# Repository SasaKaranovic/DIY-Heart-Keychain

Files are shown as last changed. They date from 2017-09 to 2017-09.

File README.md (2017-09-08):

# DIY-Heart-Keychain

Check it out on [SasaKaranovic.com/projects/diy-heart-keychain][1]

This one is a very simple but cool project, something that I would recommend to anyone who is interested into DIY electronics, gadgets and learning new stuff in general. 

It is definitely one of those projects that don’t require too much time but you can learn a lot by making it and also earn a lot of credit by sharing it with your friends and family.

### See it in action
Front side of Heart Keychain in Hand (http://sasakaranovic.com/wp-content/uploads/2017/09/InHand_Front-Preview.jpg)

Back side of Heart Keychain in Hand (http://sasakaranovic.com/wp-content/uploads/2017/09/InHand_Back-Preview.jpg)


Heart Keychain in Action (http://sasakaranovic.com/wp-content/uploads/2017/09/InHand-Raw-600px.gif)

### Schematic and PCB

Schematic (http://sasakaranovic.com/wp-content/uploads/2017/09/Schematic.png)

Schematic (http://sasakaranovic.com/wp-content/uploads/2017/09/PCB-Front-and-Back.png)

## Find out more cool projects 

Find more cool projects on my [website][1].

Also feel free to follow me on social media:
[SasaKaranovic.com][2] - [YouTube][3] - [Facebook][4] - [Twitter][5] - [LinkedIn][6]

  [1]: http://sasakaranovic.com/projects/diy-heart-keychain/
  [2]: http://sasakaranovic.com/
  [3]: http://sasakaranovic.com/youtube
  [4]: http://sasakaranovic.com/facebook
  [5]: http://sasakaranovic.com/twitter
  [6]: http://sasakaranovic.com/linkedin

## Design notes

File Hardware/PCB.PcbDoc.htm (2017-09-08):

Reporting Options

# File in Previous Format

Date | : | 2017-09-05
Time | : | 00:32:28
Filename | : | D:\_SocialMedia_\SasaKaranovic.com\GitHub\2017-09-05-DIY-Heart-Keychain\Source files\Design Files\PCB.PcbDoc

Version | Warning

This file was generated by an earlier version of the software

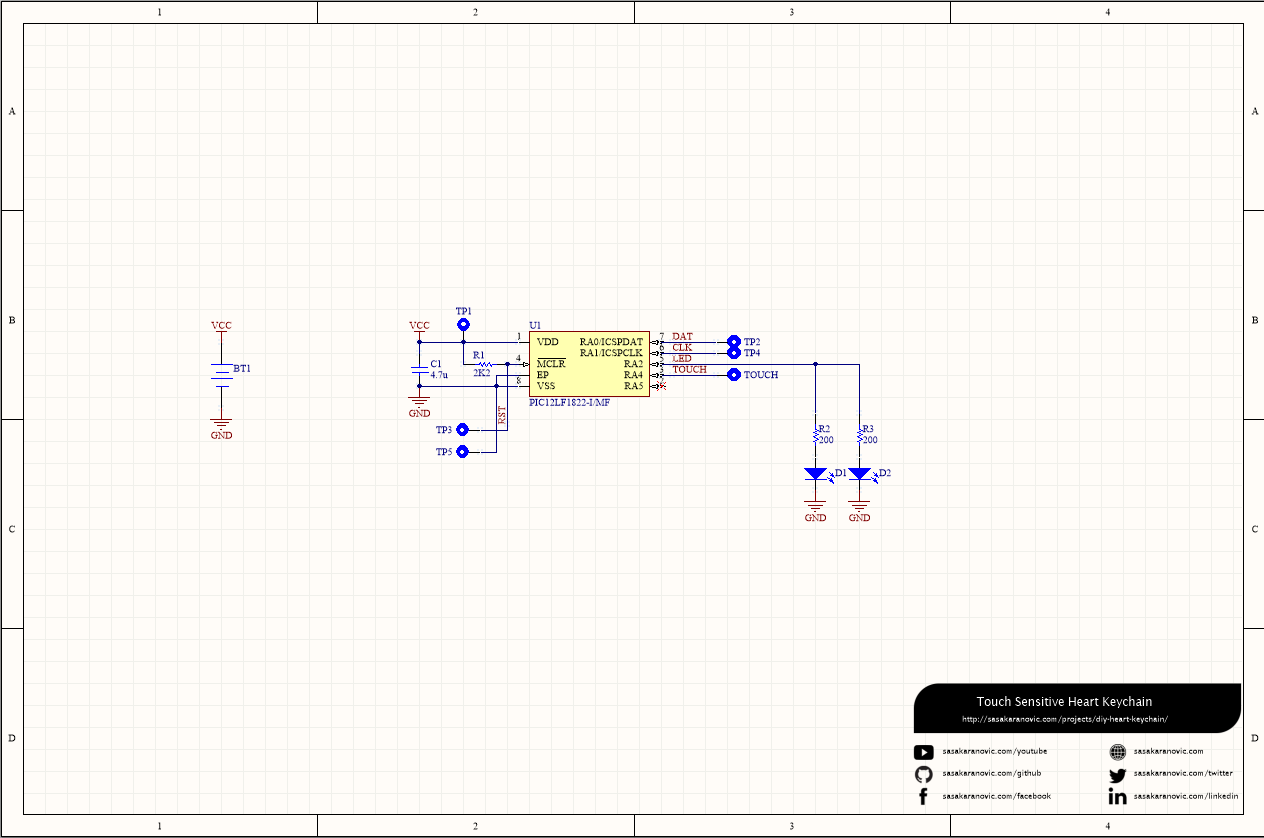
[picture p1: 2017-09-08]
Schematic.png

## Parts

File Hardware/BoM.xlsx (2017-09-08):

Designator | Quantity | Distributor | Distributor PN | Value
BT1 | 1 | Digikey | BAT-HLD-002-SMT-ND | CR2016 Battery Holder
C1 | 1 | Digikey | 1276-2087-1-ND | 4.7u
D1, D2 | 2 | Digikey | 475-1278-1-ND | RED LED
R1 | 1 | Digikey | 311-2.20KHRCT-ND | 2K2
R2, R3 | 2 | Digikey | 311-200HRTR-ND | 200R
U1 | 1 | Digikey | PIC12LF1822-I/MF-ND | PIC12LF1822

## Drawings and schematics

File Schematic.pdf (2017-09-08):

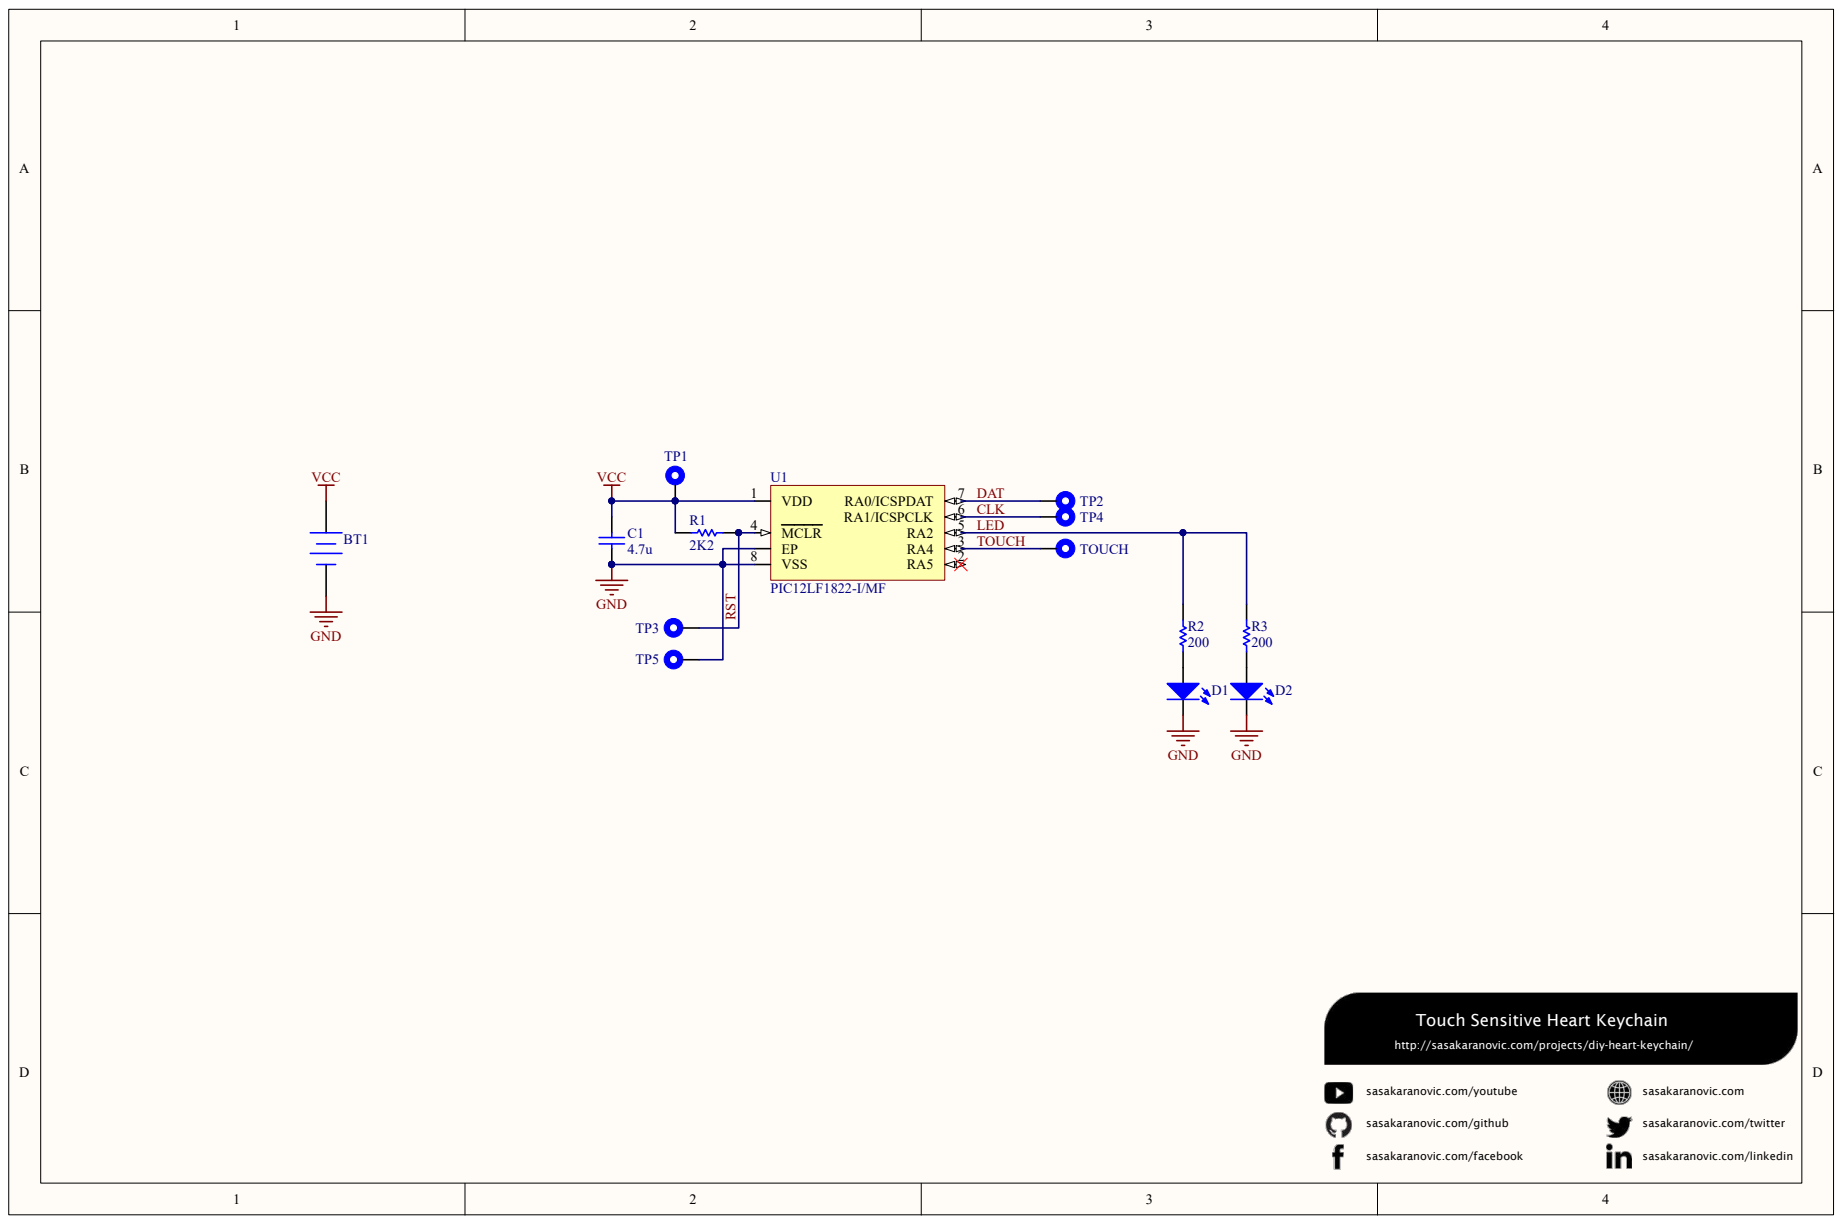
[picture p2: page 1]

Touch Sensitive Heart Keychain

http://sasakaranovic.com/projects/diy-heart-keychain/

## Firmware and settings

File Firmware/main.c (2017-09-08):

#include "main.h"

volatile uint8_t currentDC               = 0;
volatile uint8_t CapSensePrevious        = 0;
volatile uint8_t CapTMR0Cnt              = 0;
volatile uint8_t CapSenseSensitivity     = 7;
volatile uint8_t targetRed               = 0;
volatile uint8_t REDCurrent              = 0;
volatile uint8_t heartBeatCount          = 0;
volatile uint8_t delay                   = 0;
volatile uint8_t BlinkEnabled            = 0;
uint8_t fadeSide                         = 0;
uint16_t timeout                         = 0;

void main(void) {
    InitializeDevice();
    SetUpCapsense();
    SetUpTimer1();
    
    while(1) {
        if(!STATUSbits.nTO) {
            CLRWDT();
            heartBeatCount      = 0; 
            LED                 = 0;
            targetRed           = 0;
            currentDC           = 0;
            timeout             = 0;
            delay               = 0;
            timeout             = 0;
            BlinkEnabled        = 0;
            INTCONbits.PEIE     = 1;
        }
        
        if( (delay > 6) &&  (heartBeatCount > 0) && BlinkEnabled) {
            
            if(fadeSide == 1) {
                targetRed++;
            }
            else {
                targetRed--;
            }


            if(targetRed >= 254) {
                fadeSide = 0;
            }

            if(targetRed == 0) {
                fadeSide = 1;
                heartBeatCount--;
            }

            delay = 0;
            timeout = 0;
        }
        
        if(timeout >= 2000 && heartBeatCount == 0) {
            heartBeatCount      = 0; 
            LED                 = 0;
            targetRed           = 0;
            currentDC           = 0;
            delay               = 0;
            BlinkEnabled        = 0;
            INTCONbits.PEIE     = 0;
            SLEEP();
        }
        else if(timeout < 2000) {
            CLRWDT();
        }
    }
    
    return;
}

void interrupt ISRRoutine(void)
{
    //Timer0 interrupt {CAP SENSING timer}
    if(INTCONbits.TMR0IE && INTCONbits.TMR0IF) {
        INTCONbits.TMR0IF   = 0;
        TMR0                = 0;
        
//        LED = ~LED;
        
        return;
    }
    
    //Timer1 Interrupt
    //Use Timer 1 as time base
    if(PIE1bits.TMR1IE && PIR1bits.TMR1IF) {
        INTCONbits.PEIE = 0;
        PIR1bits.TMR1IF = 0;
        
        uint8_t diff;
        
        if(TMR0 < CapSensePrevious) {
            diff = CapSensePrevious - TMR0;
        }
        else { diff = TMR0 - CapSensePrevious; }
        
        if(diff < CapSenseSensitivity && !BlinkEnabled ) {
            heartBeatCount      = 3;
            BlinkEnabled        = 1;
            //CLRWDT();
        }
        else { 
//            heartBeatCount      = 0; 
//            LED                 = 0;
//            BlinkEnabled        = 0;
        }
        
        CapSensePrevious = TMR0;
        //TMR0=0;
        
        INTCONbits.PEIE = 1;
        return;
    }


    //Use Timer2 for pulsing the LED
    if(PIE1bits.TMR2IE && PIR1bits.TMR2IF) {
        PIR1bits.TMR2IF = 0;
        //INTCONbits.PEIE = 0;
        currentDC += 1;
        delay += 1;
        timeout++;
        
        if(heartBeatCount) {
            if(currentDC >= 254) { currentDC = 0; }

            if(currentDC < targetRed) { LED = 1; }
            else { LED = 0; }
        }
        else {
            currentDC   = 0;
            LED         = 0;
        }
        
        //TMR2 = 0;
        //INTCONbits.PEIE = 1;
        return;
    }
}


void InitializeDevice() 
{
    /*
            Configure device for 8MHz
     */
    //SCS<1:0>: System Clock Select bits
    OSCCONbits.SCS          = 0b00;     //00 = Clock determined by FOSC<2:0> in Configuration Word 1.

    //IRCF<3:0>: Internal Oscillator Frequency Select bits
    OSCCONbits.IRCF         = 0b1110;   //1110 = 8MHz HF

    //SPLLEN: Software PLL Enable bit   (If PLLEN in Configuration Word 1 = 0:)
    OSCCONbits.SPLLEN       = 0;        //0 = 4x PLL is disabled

    //Configure pins
    TRISLED                 = 0;
    TRISTOUCH               = 1;
    ANSELTOUCH              = 1;
    LED                     = 0;
    
    OPTION_REGbits.nWPUEN   = 1;
    WPUA                    = 0;

   /*
           Timer2 Setup for heartbeat effect
    */
   //T2OUTPS<3:0>: Timer2 Output Postscaler Select bits
   T2CONbits.T2OUTPS   = 0b0000;   //0000 = 1:1 Postscaler

   //T2CKPS<1:0>: Timer2 Clock Prescale Select bits
   T2CONbits.T2CKPS    = 0b00;     //00 = Prescaler is 1

   //TMR2ON: Timer2 On bit
   T2CONbits.TMR2ON    = 1;        //1 = Timer2 is on
   
   
   //Configure WatchDog Timer
   WDTCONbits.WDTPS = 0b01010;      //01010 = 1:32768 (Interval 1s typ)


    /*
            Configure INTERRUPT CONTROL REGISTER
    */
    PIE1bits.TMR2IE = 1;    //1 = Enables the Timer2 to PR2 match interrupt
    INTCONbits.PEIE = 1;    //1 = Enables all active peripheral interrupts
    INTCONbits.GIE  = 1;    //1 = Enables all active interrupts
}


void SetUpCapsense() 
{
    CPSCON0bits.CPSON       = 1;    //1 = CPS module is enabled
    CPSCON0bits.CPSRM       = 0;    //0 = CPS module is in the low range. Internal oscillator voltage references are used.
    CPSCON0bits.CPSRNG      = 0b01; //10 = Oscillator is in Medium Range. Charge/Discharge Current is nominally 1.2 ?A
    CPSCON1bits.CPSCH       = 0b0011;   //0011 = channel 3, (CPS3) -> RA4

    OPTION_REGbits.TMR0CS   = 1 ;    //0 = Internal instruction cycle clock (FOSC/4)
    OPTION_REGbits.PSA      = 0;    //0 = Prescaler is assigned to the Timer0 module
    CPSCON0bits.T0XCS       = 1;    //1 = Timer0 clock source is the capacitive sensing oscillator

    INTCONbits.T0IE         = 0;    //Timer0 Interrup is disabled
}


void SetUpTimer1() 
{
    /*
            Timer1 Interrupt and Enable
     */
    PIE1bits.TMR1IE     = 1;
    T1CONbits.TMR1CS    = 0b00; //00 =Timer1 clock source is instruction clock (FOSC/4)
    T1CONbits.T1CKPS    = 0b10; //11 = 1:8 Prescale value
    T1CONbits.TMR1ON    = 1;    //1 = Enables Timer1
}


uint8_t FadeInOut(uint8_t current, uint8_t up) {
    uint8_t add = 0;

    if(up == 1) {
        if( current >= 250 ) { add = 1; }
        else if( current >= 200 ) { add = 1; }
        else if (current >= 100) { add = 1; }
        else if (current >= 50)  { add = 1; }
        else { add = 1; }
        return (current+add);
    }
    else {
        if( current >= 200 ) { add = 1; }
        else if (current >= 100) { add = 1; }
        else if (current >= 50)  { add = 1; }
        else { add = 1; }

        return (current-add);
    }
}

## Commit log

2017-09-08 DIY Hear Keychain Release
    [Design your own Heart Keychain.PrjPcb, PCB.PcbDoc, Schematic.SchDoc]
2017-09-08 Including BoM
    [BoM.xlsx, Design your own Heart Keychain.PrjPcb, Schematic.SchDoc]
